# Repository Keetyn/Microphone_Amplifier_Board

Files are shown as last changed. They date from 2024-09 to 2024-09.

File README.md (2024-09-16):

# Microphone_Amplifier_Board

This is an audio amplifier board capable of taking any small audio signal, differential or singled ended and amplifying it to an output of 30W @ 8 ohms. This was designed, built, and tested as more of an educational exercise than anything else and thus relies on screw terminal inputs for power and requires external power supplies. This is a 4-layer board with the two inner copper layers being used as Ground planes.

The board can be thought of as having four distinct sections:

1. the first is a THAT 1510 instrumentation amplifier with a tunable gain that is meant to take in a signal       from either a microphone or an aux cord. This amplifies the signal by a gain of anywhere from +32 - +62dB      depending on the position of the gain potentiometer. This input can accept a differential or single    
   ended input.
2. The second is the EQ filter. This is a state variable topology filter. This implementation provides         
   potentiometers that allow the user to adjust the damping (alpha), Center Frequency (Fo), Gain (A), and a 
   latching pushbutton that can enable or disable the filter. Fo can be adjusted from 300Hz - 2.2kHz.             alpha can be adjusted from 0.5 - 10. Gain can be adjusted from -40dB - +15dB
3. The third is a Peak Limiter using a THAT 4305 Compander IC. This is a versatile analog processing IC that with the accompanying circuitry and potentiometers acts as a non-distorting peak limiter with the ability to adjust the compression threshold and compression ratio. The threshold can be adjusted from +7.3dBV - +9.74dBV. The compression ratio can also be adjusted anywhere from infinity:1 to a value approaching 1:1.
4. THe final section of this board is a TPA3122 Class-D analog input power amplifier. This IC is capable of outputting 30W and has an accompanying potentiometer that can be used to attenuate its input as a volume control.

Microphone_Amplifier_Flowchart

Each of the above listed sections is split apart by 100 mil pin headers that completely break any connection between the sections. This was done for easier test and troubleshooting and to help compartmentalize individual portions of the board. Below is a screenshot of a 3D render of the board in KiCad with each section clearly separate with silkscreen lines and labels.

KiCad_PCB_Render

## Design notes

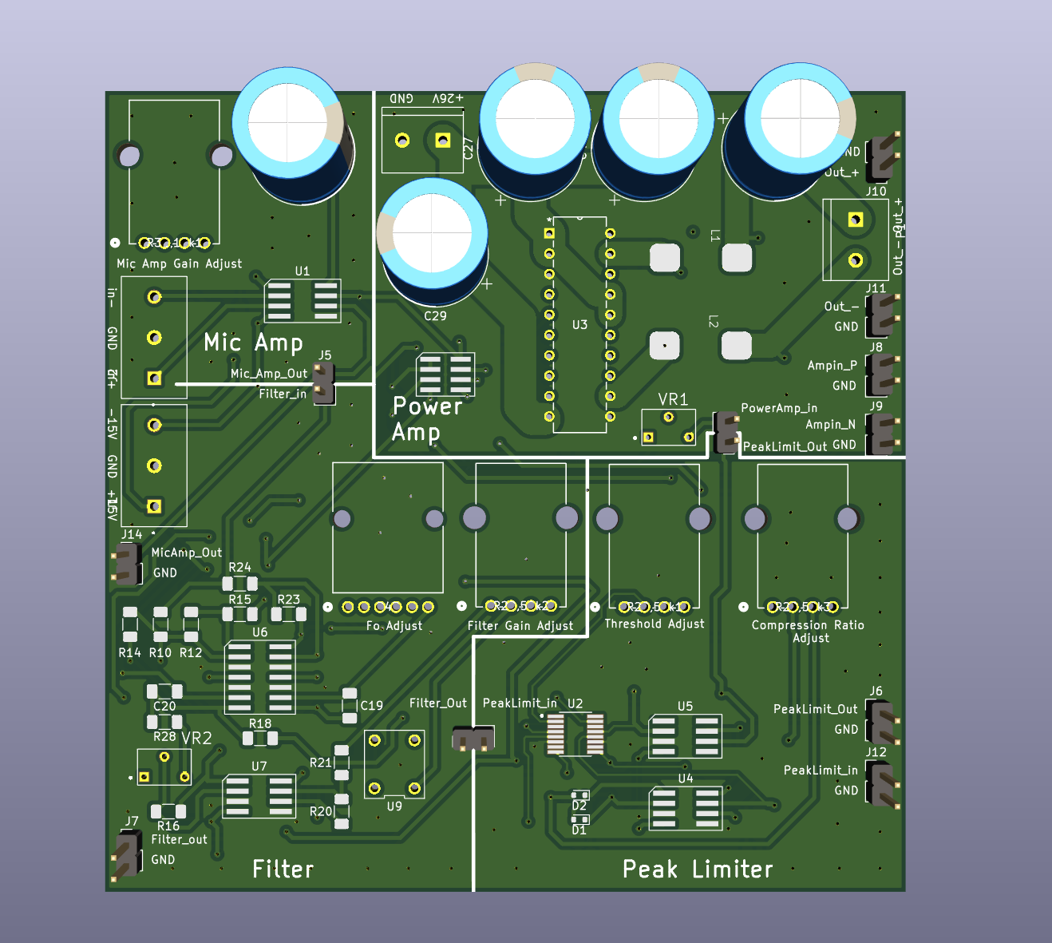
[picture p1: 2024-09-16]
ReadMe_Images/KiCad_PCB_Render.png

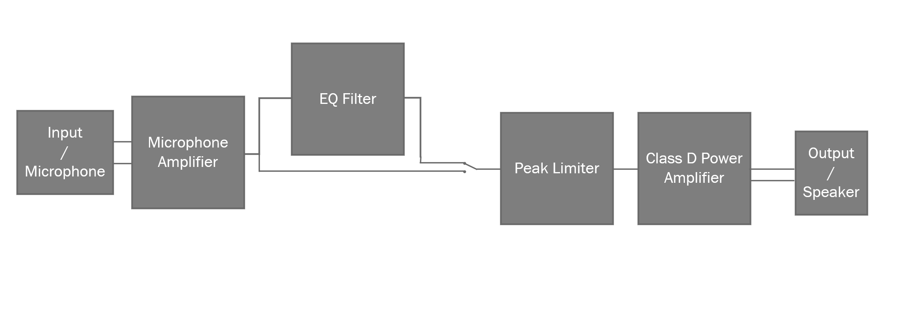
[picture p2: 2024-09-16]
ReadMe_Images/Microphone_Amplifier_Flowchart.png

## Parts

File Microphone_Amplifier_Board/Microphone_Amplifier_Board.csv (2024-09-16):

Source: | C:\Users\KjB22\Desktop\Test Kicad\318_Project_R5\318_Project_R5\318_Project_R5.kicad_sch
Date: | 4/11/2024 16:19
Tool: | Eeschema 7.0.7
Generator: | C:\Program Files\KiCad\7.0\bin\scripting\plugins/bom_csv_grouped_by_value.py
Component Count: | 119
Collated Components:
Item | Qty | Reference(s) | Value | LibPart | Footprint | Datasheet | DNP | AVAILABILITY | Availability | Check_prices | Comment | DESCRIPTION | Description | DigiKey_Part_Number | MANUFACTURER | MF | MP | PACKAGE | PARTREV | PRICE | Package | Price | Purchase-URL | STANDARD | Sim.Device | Sim.Pins | SnapEDA_Link
1 | 4 | C1, C27, C29, C46 | 470uF | Device:C | Capacitor_THT:CP_Radial_D13.0mm_P5.00mm | ~
2 | 21 | C2, C3, C8, C9, C10, C11, C15, C16, C17, C18, C22, C28, C32, C41, C42, C45, C47, C49, C50, C51, C53 | 100nF | Device:C | Capacitor_SMD:C_1206_3216Metric_Pad1.33x1.80mm_HandSolder | ~
3 | 6 | C4, C7, C13, C37, C40, C44 | 22uF | Device:C | Capacitor_SMD:C_1206_3216Metric_Pad1.33x1.80mm_HandSolder | ~
4 | 4 | C5, C38, C39, C43 | 220pF | Device:C | Capacitor_SMD:C_1206_3216Metric_Pad1.33x1.80mm_HandSolder | ~
5 | 4 | C6, C24, C26, C33 | 10uF | Device:C | Capacitor_SMD:C_1206_3216Metric_Pad1.33x1.80mm_HandSolder | ~
6 | 1 | C12 | 22pF | Device:C | Capacitor_SMD:C_1206_3216Metric_Pad1.33x1.80mm_HandSolder | ~
7 | 2 | C19, C20 | 47nF | Device:C | Capacitor_SMD:C_1206_3216Metric_Pad1.33x1.80mm_HandSolder | ~
8 | 2 | C23, C25 | 1uF | Device:C | Capacitor_SMD:C_1206_3216Metric_Pad1.33x1.80mm_HandSolder | ~
9 | 2 | C30, C31 | 220nF | Device:C | Capacitor_SMD:C_1206_3216Metric_Pad1.33x1.80mm_HandSolder | ~
10 | 2 | C34, C35 | 680nF | Device:C | Capacitor_SMD:C_1206_3216Metric_Pad1.33x1.80mm_HandSolder | ~
11 | 1 | C36 | 22p | Device:C | Capacitor_SMD:C_1206_3216Metric_Pad1.33x1.80mm_HandSolder | ~
12 | 1 | C48 | 1000uF | Device:C | Capacitor_THT:CP_Radial_D13.0mm_P5.00mm | ~
13 | 2 | C52, C54 | 1nF | Device:C | Capacitor_SMD:C_1206_3216Metric_Pad1.33x1.80mm_HandSolder | ~
14 | 2 | D1, D2 | 1N914WT | Diode:1N914WT | Diode_SMD:D_SOD-523 | http://www.mouser.com/ds/2/149/1N4148WT-461550.pdf |  |  |  |  |  |  |  |  |  |  |  |  |  |  |  |  |  |  | D | 1=K 2=A
15 | 2 | J1, J2 | 282837-3 | 3 Terminal Wire clamp Connector:282837-3 | 282837_3 Screw Terminal:TE_282837-3 |  |  |  |  | https://www.snapeda.com/parts/282837-3/TE+Connectivity+AMP+Connectors/view-part/?ref=eda | 282837-3 |  | Terminal Block Connector,PCB,3,5.08 mm,Front,30-16 AWG,Green,13.5 A,250 V | TE Connectivity 282837-3 | A113321-ND | TE CONNECTIVITY | TE Connectivity | 282837-3 |  | H |  | None |  | https://www.snapeda.com/api/url_track_click_mouser/?unipart_id=2765182&manufacturer=TE Connectivity&part_name=282837-3&search_term=None | Manufacturer Recommendations |  |  | https://www.snapeda.com/parts/282837-3/TE+Connectivity+AMP+Connectors/view-part/?ref=snap
 |  |  |  |  |  | ~
17 | 2 | L1, L2 | 10u | Device:L | Winbond 2Gbit Flash SPI:Power Inductor 10uH | ~
18 | 2 | P1, P2 | 282837-2 | 2 Terminal Wire clamp Connector:282837-2 | 282837_2 Screw Terminal:TE_282837-2 |  |  | Good |  | https://www.snapeda.com/parts/282837-2/TE+Connectivity+AMP+Connectors/view-part/?ref=eda | 282837-2 | TERMINAL BLOCK 3.5MM 2POS PCB | Terminal Block Connector Wire Receptacle 2 5.08 mm 30-16 AWG Green 13.5 A 250 V | TE Connectivity 282837-2 | A113320-ND |  | TE Connectivity | 282837-2 | None | G3 | 0.28 USD | None |  | https://www.snapeda.com/api/url_track_click_mouser/?unipart_id=2549980&manufacturer=TE Connectivity&part_name=282837-2&search_term=None |  |  |  | https://www.snapeda.com/parts/282837-2/TE+Connectivity+AMP+Connectors/view-part/?ref=snap
19 | 2 | R1, R2 | 330 | Device:R | Resistor_SMD:R_1206_3216Metric_Pad1.30x1.75mm_HandSolder | ~
20 | 4 | R3, R4, R21, R28 | 1k | Device:R | Resistor_SMD:R_1206_3216Metric_Pad1.30x1.75mm_HandSolder | ~
21 | 2 | R5, R7 | 20k | Device:R | Resistor_SMD:R_1206_3216Metric_Pad1.30x1.75mm_HandSolder | ~
22 | 1 | R6 | 5k1 | Device:R | Resistor_SMD:R_1206_3216Metric_Pad1.30x1.75mm_HandSolder | ~
23 | 14 | R8, R10, R12, R13, R14, R16, R19, R20, R30, R31, R34, R35, R39, R42 | 10k | Device:R | Resistor_SMD:R_1206_3216Metric_Pad1.30x1.75mm_HandSolder | ~
24 | 1 | R9 | 309k | Device:R | Resistor_SMD:R_1206_3216Metric_Pad1.30x1.75mm_HandSolder | ~
25 | 2 | R15, R18 | 1.5k | Device:R | Resistor_SMD:R_1206_3216Metric_Pad1.30x1.75mm_HandSolder | ~
26 | 4 | R22, R23, R24, R40 | 6.98k | Device:R | Resistor_SMD:R_1206_3216Metric_Pad1.30x1.75mm_HandSolder | ~
27 | 3 | R29,50k1, R29,50k2, R29,50k3 | PTV111-4420A-B104 | PTT111-3 Potentiometer:PTT111-3217A-B503 | PTV111:PTT111-3_17_BRN | PTT111-3217A-B503
28 | 1 | R31,10k1 | PTT111-3415A-B103 | PTT111-3 Potentiometer:PTT111-3217A-B503 | PTV111:PTT111-3_17_BRN | PTT111-3217A-B503
29 | 2 | R32, R33 | 4.7k | Device:R | Resistor_SMD:R_1206_3216Metric_Pad1.30x1.75mm_HandSolder | ~
30 | 1 | R43 | PTV112-1417A-A103 | PTV112 Dual Gang Potentiometer:PTV112-4420A-B503 | PTV112:PTV112-4_BRN | PTV112-4420A-B503
31 | 1 | U1 | THAT 1510 | Custom Symbols:THAT_1510_SO8 | Custom Footprints:THAT 1510 SO8
32 | 1 | U2 | 4305Q16-U | THAT 4305Q16-U:4305Q16-U | 4305Q16-U:SOP63P599X175-16N |  |  |  | In Stock | https://www.snapeda.com/parts/4305Q16-U/THAT+Corporation/view-part/?ref=eda |  |  | Audio Amplifiers Pre-Trimmed Analog Engine IC - QSOP16 |  | THAT Corporation | THAT Corporation | 4305Q16-U |  | 10 |  | None | None |  | IPC-7351B |  |  | https://www.snapeda.com/parts/4305Q16-U/THAT+Corporation/view-part/?ref=snap
33 | 1 | U3 | TPA3122D2N | TPA3122 Class D Amp:TPA3122D2N | TPA3122:N20 | TPA3122D2N
34 | 2 | U4, U7 | TL082 | Amplifier_Operational:TL082 |  | http://www.ti.com/lit/ds/symlink/tl081.pdf
35 | 1 | U5 | TL081 | Amplifier_Operational:TL081 |  | http://www.ti.com/lit/ds/symlink/tl081.pdf
36 | 1 | U6 | TL084 | Amplifier_Operational:TL084 |  | http://www.ti.com/lit/ds/symlink/tl081.pdf
37 | 1 | U9 | ~ | Custom Symbols:Latching_Pushbutton
38 | 1 | U10 | TL082 | Amplifier_Operational:TL082 | Winbond 2Gbit Flash SPI:TL081 SOIC-8 | http://www.ti.com/lit/ds/symlink/tl081.pdf
39 | 2 | VR1, VR2 | 3266W-1-203 | 20k Trim Pot:3266W-1-203 | 20k Trim Pot:TRIM_3266W-1-203 |  |  |  | In Stock | https://www.snapeda.com/parts/3266W-1-203/Bourns/view-part/?ref=eda |  |  | TRIMMER-1/4in SQ MT CERMET | Bourns 3266W-1-203 |  | Bourns | Bourns | 3266W-1-203 |  |  |  | TO-218 Bourns | None |  | IPC7251 |  |  | https://www.snapeda.com/parts/3266W-1-203/Bourns/view-part/?ref=snap

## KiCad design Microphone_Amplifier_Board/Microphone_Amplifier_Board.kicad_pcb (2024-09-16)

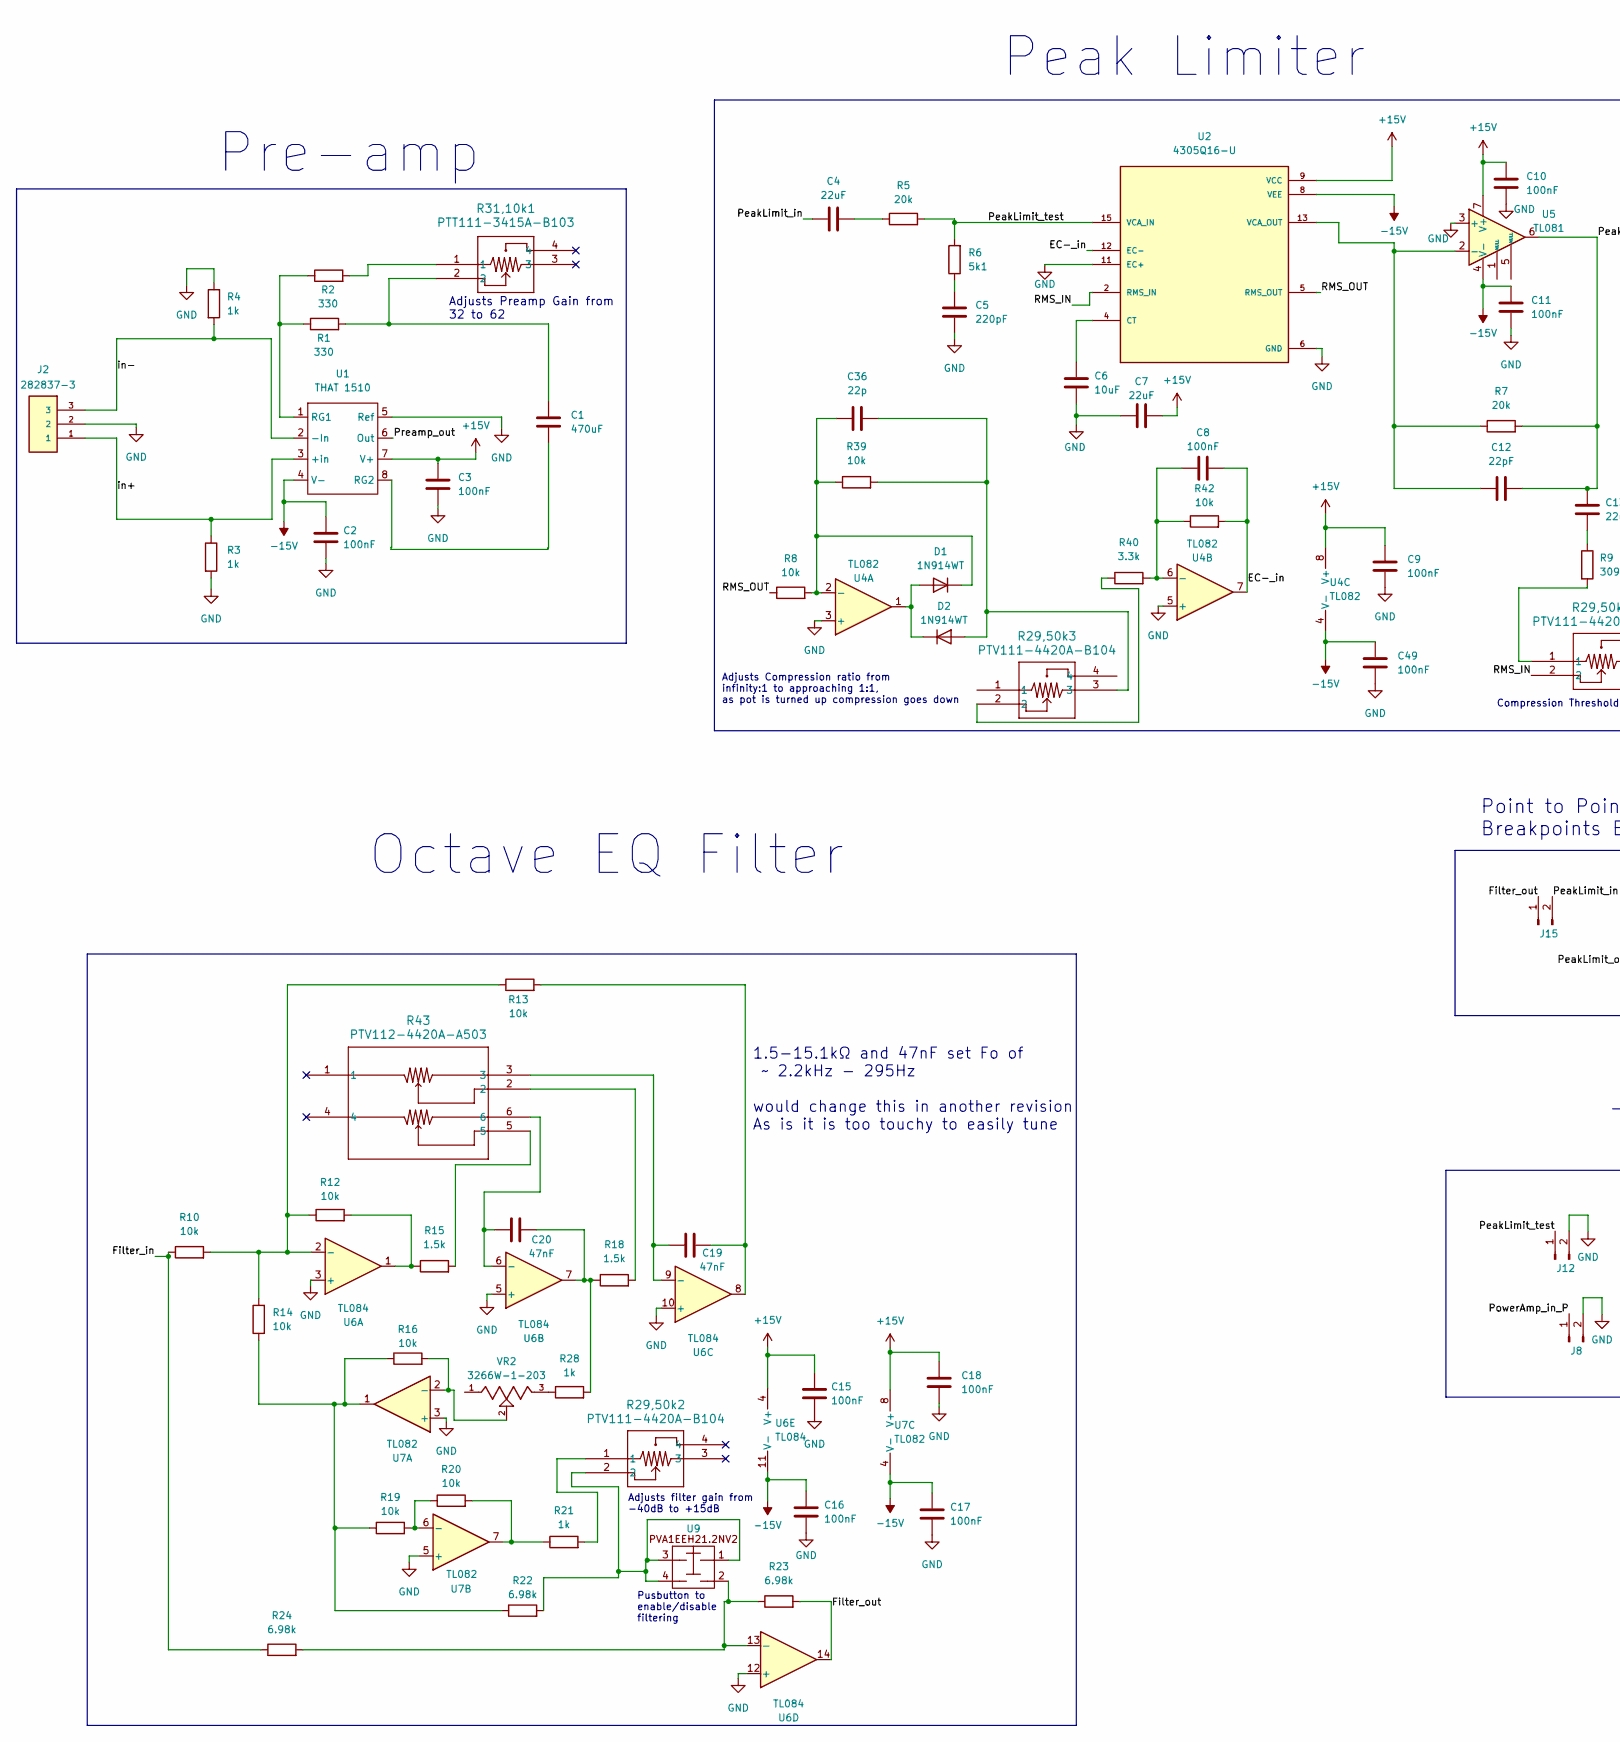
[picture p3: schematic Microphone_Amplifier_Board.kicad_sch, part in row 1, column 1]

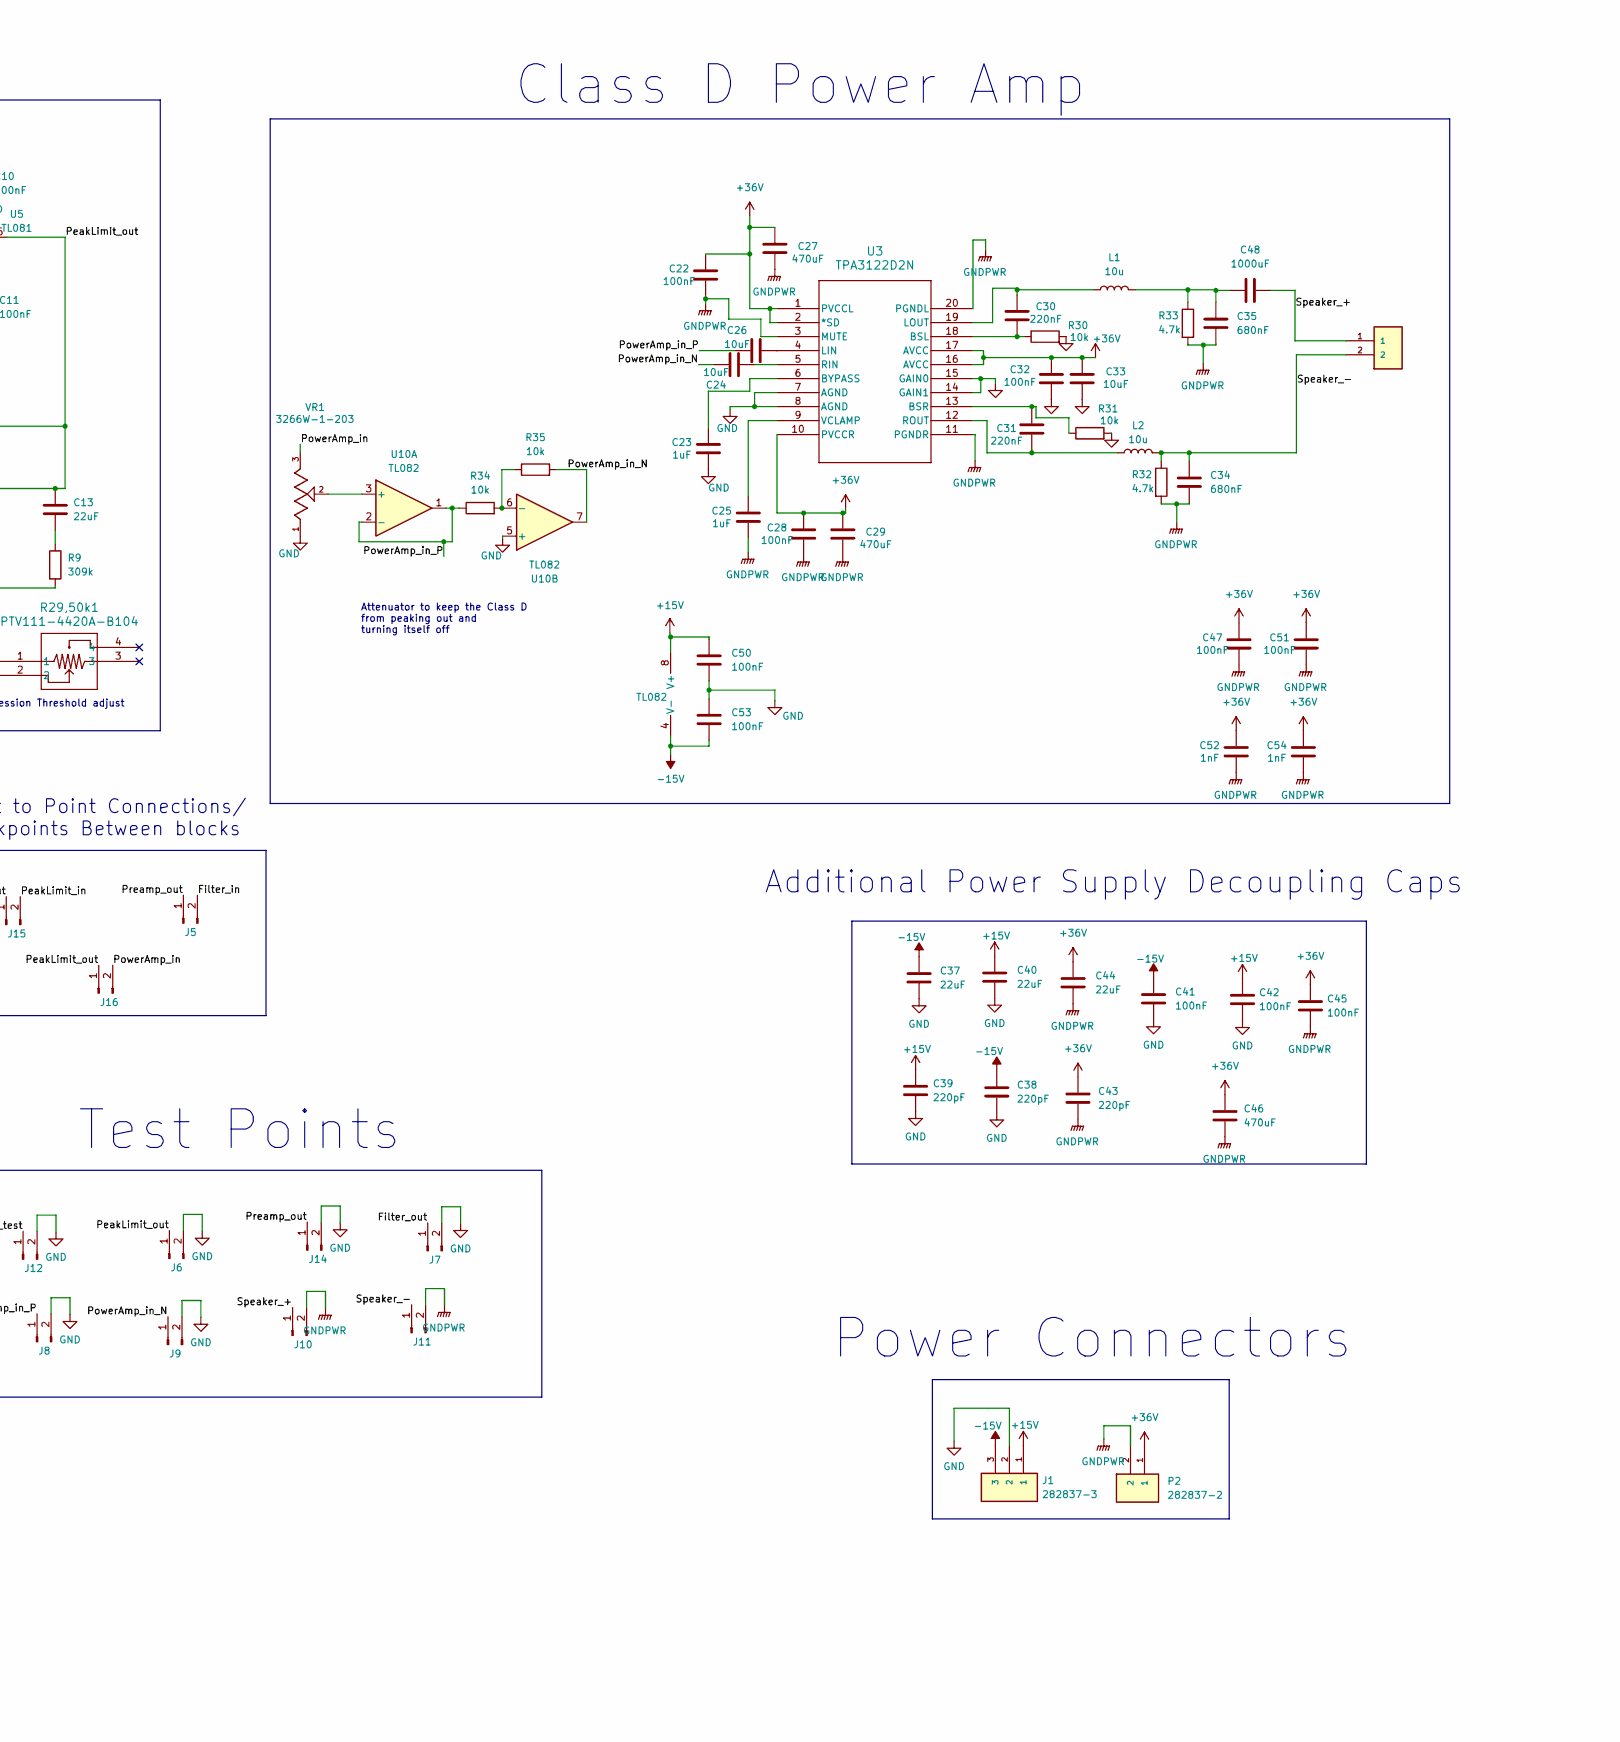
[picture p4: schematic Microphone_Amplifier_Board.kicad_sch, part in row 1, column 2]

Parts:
C1, C27, C29, C46: 470uF; CP_Radial_D13.0mm_P5.00mm
C2, C3, C8, C9, C10, C11, C15, C16, C17, C18, C22, C28, C32, C41, C42, C45, C47, C49, C50, C51, C53: 100nF; C_1206_3216Metric_Pad1.33x1.80mm_HandSolder
C4, C7, C13, C37, C40, C44: 22uF; C_1206_3216Metric_Pad1.33x1.80mm_HandSolder
C5, C38, C39, C43: 220pF; C_1206_3216Metric_Pad1.33x1.80mm_HandSolder
C6, C24, C26, C33: 10uF; C_1206_3216Metric_Pad1.33x1.80mm_HandSolder
C12: 22pF; C_1206_3216Metric_Pad1.33x1.80mm_HandSolder
C19, C20: 47nF; C_1206_3216Metric_Pad1.33x1.80mm_HandSolder
C23, C25: 1uF; C_1206_3216Metric_Pad1.33x1.80mm_HandSolder
C30, C31: 220nF; C_1206_3216Metric_Pad1.33x1.80mm_HandSolder
C34, C35: 680nF; C_1206_3216Metric_Pad1.33x1.80mm_HandSolder
C36: 22p; C_1206_3216Metric_Pad1.33x1.80mm_HandSolder
C48: 1000uF; CP_Radial_D13.0mm_P5.00mm
C52, C54: 1nF; C_1206_3216Metric_Pad1.33x1.80mm_HandSolder
D1, D2: 1N914WT; D_SOD-523
J1, J2: 282837-3; TE_282837-3; PARTREV H; DigiKey_Part_Number A113321-ND
J5, J6, J7, J8, J9, J10, J11, J12, J14, J15, J16: Conn_01x02_Pin; PinHeader_1x02_P2.54mm_Vertical
L1, L2: 10u; Power Inductor 10uH
P1, P2: 282837-2; TE_282837-2; PARTREV G3; DigiKey_Part_Number A113320-ND
R1, R2: 330; R_1206_3216Metric_Pad1.30x1.75mm_HandSolder
R3, R4, R21, R28: 1k; R_1206_3216Metric_Pad1.30x1.75mm_HandSolder
R5, R7: 20k; R_1206_3216Metric_Pad1.30x1.75mm_HandSolder
R6: 5k1; R_1206_3216Metric_Pad1.30x1.75mm_HandSolder
R8, R10, R12, R13, R14, R16, R19, R20, R30, R31, R34, R35, R39, R42: 10k; R_1206_3216Metric_Pad1.30x1.75mm_HandSolder
R9: 309k; R_1206_3216Metric_Pad1.30x1.75mm_HandSolder
R15, R18: 1.5k; R_1206_3216Metric_Pad1.30x1.75mm_HandSolder
R22, R23, R24: 6.98k; R_1206_3216Metric_Pad1.30x1.75mm_HandSolder
R29,50k1, R29,50k2, R29,50k3: PTV111-4420A-B104; PTT111-3_17_BRN
R31,10k1: PTT111-3415A-B103; PTT111-3_17_BRN
R32, R33: 4.7k; R_1206_3216Metric_Pad1.30x1.75mm_HandSolder
R40: 3.3k; R_1206_3216Metric_Pad1.30x1.75mm_HandSolder
R43: PTV112-4420A-A503; PTV112-4_BRN
U1: THAT 1510
U2: 4305Q16-U; PARTREV 10
U3: TPA3122D2N; N20
U4, U7: TL082
U5: TL081
U6: TL084
U9: (no value)
U10: TL082; TL081 SOIC-8
VR1, VR2: 3266W-1-203; TRIM_3266W-1-203

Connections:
+15V: C3.1, C7.2, C9.2, C10.1, C15.1, C18.1, C39.1, C40.1, C42.1, C50.1, J1.1, U1.7 (V+), U2.9 (VCC), U4.8 (V+), U5.7 (V+), U6.4 (V+), U7.8 (V+), U10.8 (V+)
+36V: C22.1, C27.1, C28.1, C29.1, C32.1, C33.1, C43.1, C44.1, C45.1, C46.1, C47.1, C51.1, C52.1, C54.1, P2.1, U3.1 (PVCCL), U3.2 (*SD), U3.10 (PVCCR), U3.16 (AVCC), U3.17 (AVCC)
-15V: C2.1, C11.1, C16.1, C17.1, C37.1, C38.1, C41.1, C49.2, C53.2, J1.3, U1.4 (V-), U2.8 (VEE), U4.4 (V-), U5.4 (V-), U6.11 (V-), U7.4 (V-), U10.4 (V-)
/EC-_in: C8.2, R42.2, U2.12 (EC-), U4.7
/Filter_in: J5.2, R10.1, R24.1
/Filter_out: J7.1, J15.1, R23.2, U6.14
/PeakLimit_in: C4.1, J15.2
/PeakLimit_out: C12.2, C13.1, J6.1, J16.1, R7.2, U5.6
/PeakLimit_test: J12.1, R5.2, R6.2, U2.15 (VCA_IN)
/PowerAmp_in: J16.2, VR1.3
/PowerAmp_in_N: C24.2, J9.1, R35.2, U10.7
/PowerAmp_in_P: C26.2, J8.1, R34.1, U10.1, U10.2 (-)
/Preamp_out: J5.1, J14.1, U1.6 (Out)
/RMS_IN: R29,50k1.2, U2.2 (RMS_IN)
/RMS_OUT: R8.1, U2.5 (RMS_OUT)
/Speaker_+: C48.2, J10.1, P1.1
/Speaker_-: C34.1, J11.1, L2.2, P1.2, R32.1
/in+: J2.1, R3.1, U1.3 (+in)
/in-: J2.3, R4.2, U1.2 (-In)
GND: C2.2, C3.2, C5.2, C6.2, C7.1, C9.1, C10.2, C11.2, C15.2, C16.2, C17.2, C18.2, C23.2, C32.2, C33.2, C37.2, C38.2, C39.2, C40.2, C41.2, C42.2, C49.1, C50.2, C53.1, J1.2, J2.2, J6.2, J7.2, J8.2, J9.2, J12.2, J14.2, R3.2, R4.1, R30.2, R31.2, U1.5 (Ref), U2.6 (GND), U2.11 (EC+), U3.7 (AGND), U3.8 (AGND), U3.14 (GAIN1), U3.15 (GAIN0), U4.3 (+), U4.5 (+), U5.3 (+), U6.3 (+), U6.5 (+), U6.10 (+), U6.12 (+), U7.3 (+), U7.5 (+), U10.5 (+), VR1.1
GNDPWR: C22.2, C25.2, C27.2, C28.2, C29.2, C34.2, C35.2, C43.2, C44.2, C45.2, C46.2, C47.2, C51.2, C52.2, C54.2, J10.2, J11.2, P2.2, R32.2, R33.2, U3.3 (MUTE), U3.11 (PGNDR), U3.20 (PGNDL)
unnamed: C1.1, R1.2, R31,10k1.2
unnamed: C4.2, R5.1
unnamed: C5.1, R6.1
unnamed: C13.2, R9.1
unnamed: C19.2, R13.2, U6.8
unnamed: C20.2, R18.1, R28.2, U6.7
unnamed: C35.1, C48.1, L1.2, R33.1
unnamed: D1.2 (A), D2.1 (K), U4.1
unnamed: C36.1, D1.1 (K), R8.2, R39.1, U4.2 (-)
unnamed: C36.2, D2.2 (A), R29,50k3.3, R39.2
unnamed: R2.2, R31,10k1.1
unnamed: R12.2, R15.1, U6.1
unnamed: R14.1, R16.1, R19.1, R22.1, U7.1
unnamed: R15.2, R43.5
unnamed: R18.2, R43.2
unnamed: R20.2, R21.1, U7.7
unnamed: R21.2, R29,50k2.1
unnamed: R22.2, R29,50k2.2, U9.1, U9.3, U9.4
unnamed: R28.1, VR2.3
unnamed: R9.2, R29,50k1.1
unnamed: R29,50k3.2, R40.1
unnamed: R1.1, R2.1, U1.1 (RG1)
unnamed: C1.2, U1.8 (RG2)
unnamed: C6.1, U2.4 (CT)
unnamed: C12.1, R7.1, U2.13 (VCA_OUT), U5.2 (-)
unnamed: C30.2, R30.1, U3.18 (BSL)
unnamed: C31.1, R31.1, U3.13 (BSR)
unnamed: C23.1, U3.6 (BYPASS)
unnamed: C26.1, U3.4 (LIN)
unnamed: C30.1, L1.1, U3.19 (LOUT)
unnamed: C24.1, U3.5 (RIN)
unnamed: C31.2, L2.1, U3.12 (ROUT)
unnamed: C25.1, U3.9 (VCLAMP)
unnamed: C8.1, R40.2, R42.1, U4.6 (-)
unnamed: R10.2, R12.1, R13.1, R14.2, U6.2 (-)
unnamed: C20.1, R43.6, U6.6 (-)
unnamed: C19.1, R43.3, U6.9 (-)
unnamed: R23.1, R24.2, U6.13 (-), U9.2
unnamed: R16.2, U7.2 (-), VR2.2
unnamed: R19.2, R20.1, U7.6 (-)
unnamed: U10.3 (+), VR1.2
unnamed: R34.2, R35.1, U10.6 (-)

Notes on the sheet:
Pusbutton to enable/disable filtering
Compression Threshold adjust
Adjusts filter gain from -40dB to +15dB
Test Points
Peak Limiter
Class D Power Amp
Power Connectors
Additional Power Supply Decoupling Caps
Octave EQ Filter
Attenuator to keep the Class D from peaking out and turning itself off
Point to Point Connections/ Breakpoints Between blocks
Adjusts Compression ratio from infinity:1 to approaching 1:1, as pot is turned up compression goes down
1.5-15.1kΩ and 47nF set Fo of ~ 2.2kHz - 295Hz would change this in another revision As is it is too touchy to easily tune
Adjusts Preamp Gain from 32 to 62
Pre-amp

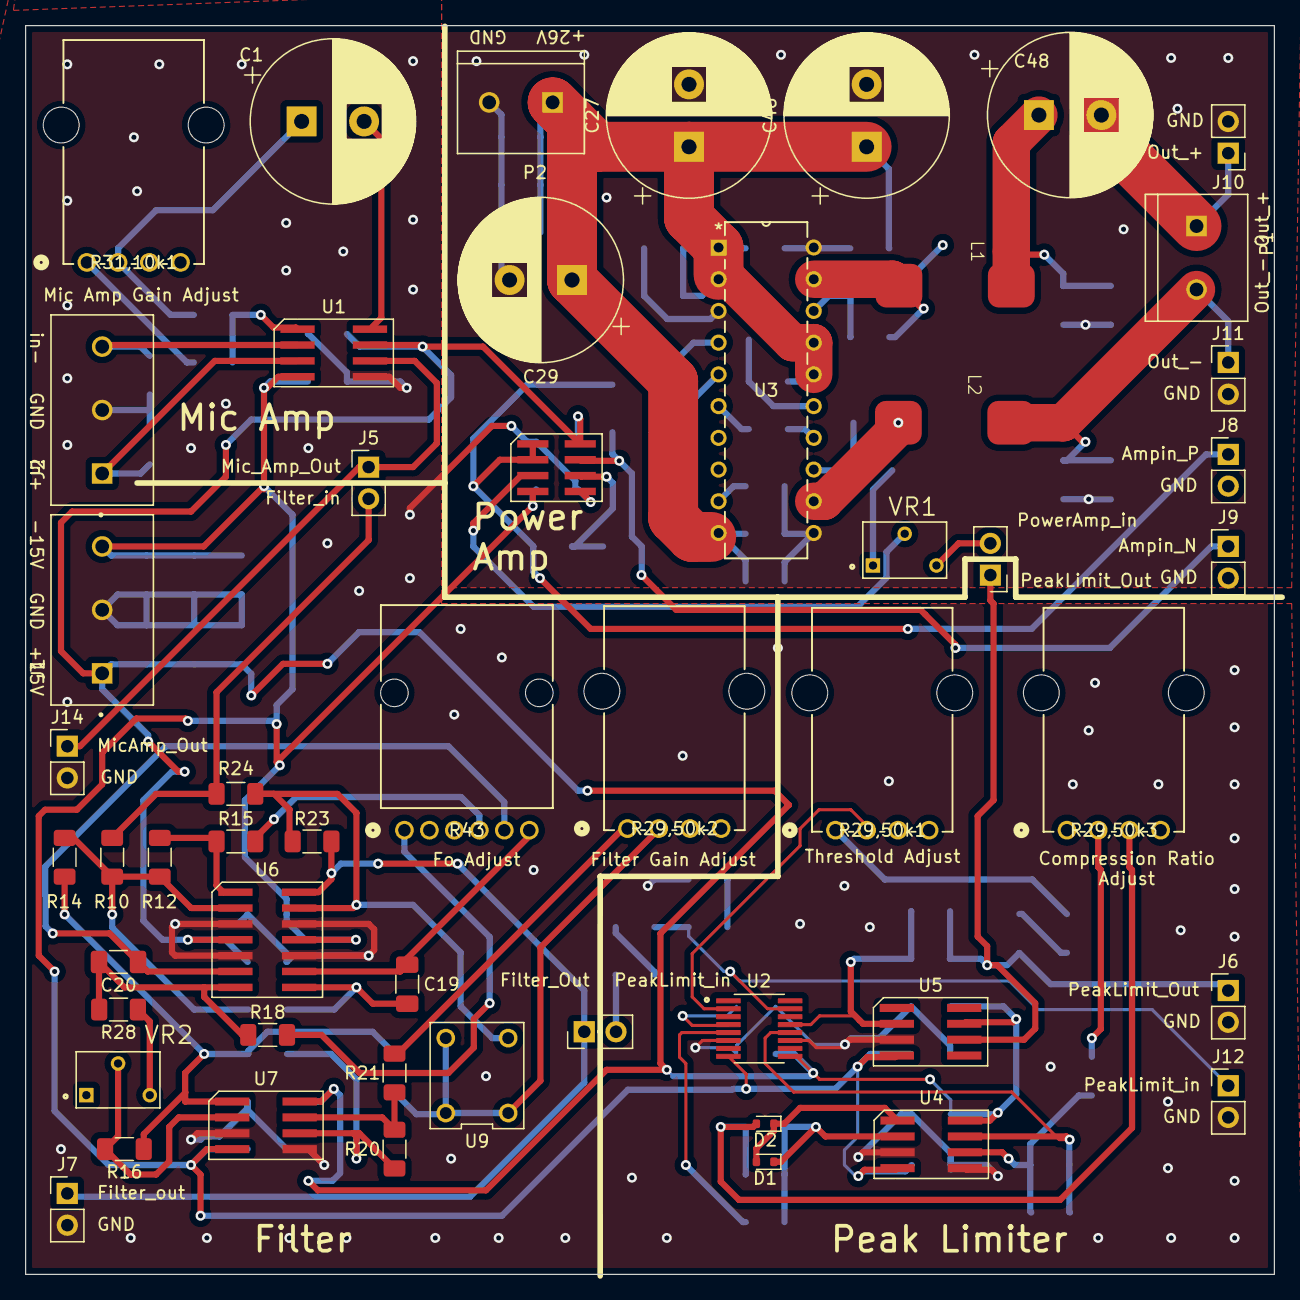
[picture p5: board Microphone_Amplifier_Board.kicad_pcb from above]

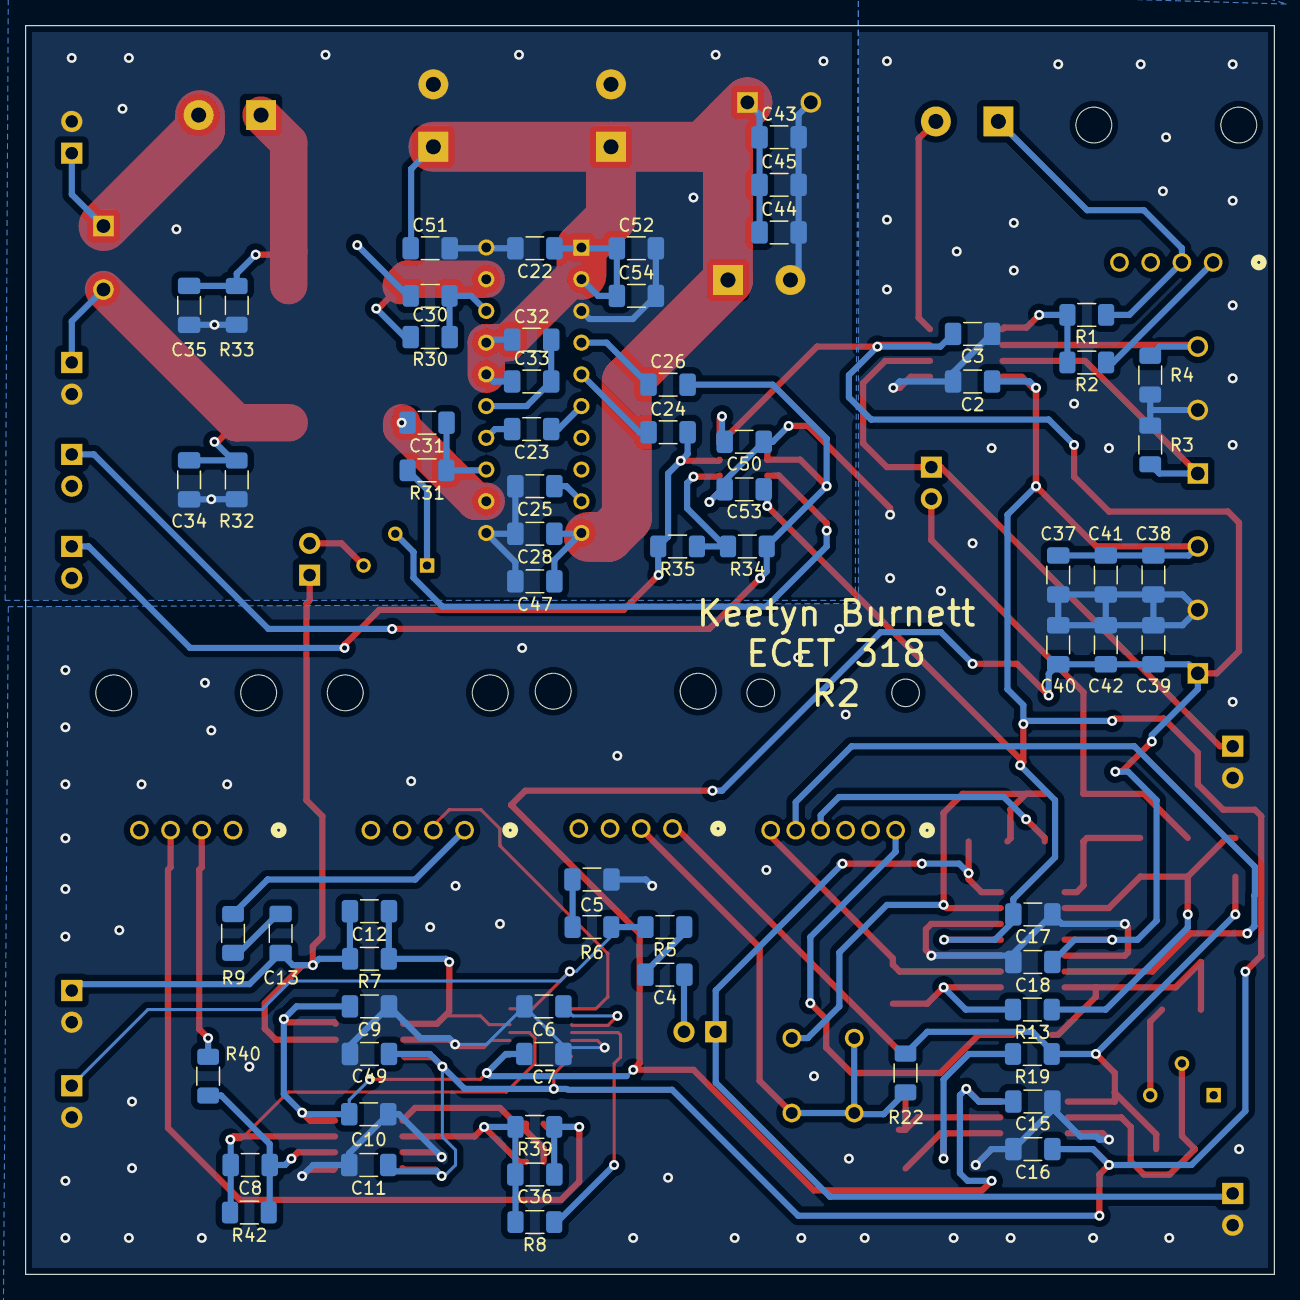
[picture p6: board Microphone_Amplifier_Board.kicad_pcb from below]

Board: 4 copper layers, 100.0 x 100.0 mm, 119 parts (66 on the bottom side), 63 nets.
